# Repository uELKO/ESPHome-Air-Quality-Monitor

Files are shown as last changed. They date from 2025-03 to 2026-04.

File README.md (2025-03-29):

Unbenannt

## Project outline
This project describes a sensor for measuring indoor air quality with power supply via USB-C.

An “Environmental Sensor Node for Air Quality Applications” from Sensirion is used. An ESP32-S3 is responsible for sensor evaluation and wireless connection via WLAN. The mounted modules are listed in the “List of Materials” section.
The housing consists of 3 parts, which can be easily 3D printed. The STEP files are stored in the “3d-models” folder.
The measured values are displayed via the ESPHome integration in Home Assistant and optionally via an e-paper display on the front.

The aim was to develop both a stationary sensor for determining indoor air quality and a mobile sensor for use on the move. The applications range from use as an informative sensor to warning messages when limit values are exceeded or as a sensor for controlling temperature and room air.

## Features
Depending on the model of the Sensirion sensor, different physical quantities can be obtained.
In this project, the SEN66 was used, which records the following measured variables:
- Temperature
- Relative humidity
- Particulate matter (PM1.0, PM2.5, PM4.0, PM10.0)
- VOC
- NOx
- CO2

In addition, there are further virtual sensors through the ESPHome yaml:
- PM ≤10 µm: Sum of the dust particle concentration
- TVOC according to Mølhave
- IAQ index (parameterizable weighting of CO2, TVOC and PM)

All sensor values are updated every 10 seconds, so this sensor is also ideal for creating fast control loops with other devices, e.g:
- Air purifiers
- Radiator valves
- Air conditioning systems

## List of Materials
- MCU:      Seeed Studio XIAO ESP32S3
- Display:  Waveshare 2.13inch E-Ink display HAT
- Sensor:   Sensirion SEN66

-> The total cost is around 70-80€.

Assembly instructions (note: in progress, only photos for now): [assembly_guide.md](docs/assembly_guide.md)

## Limitations
Status: March 2025
- Native temperature compensation not working -> deduction of a linear offset for temperature and humidity, resulting in two virtual sensors (Ambient Temperature, Ambient Humidity)
- Fan Auto Clean not working
- Official ESPHome integration “SEN5x” does not support the SEN6x series, therefore use the repo from Tobias Stanzel (https://github.com/tuct) Thank you!
-> I have made an adjustment so that e.g. the measured value PM4 only represents the range of 2.5-4 µm and not 0-4µm as originally.
- The SEN66 has an integrated air pressure sensor, which currently cannot be read out either

-> I hope for an official integration of the SEN6x series in ESPHome soon!

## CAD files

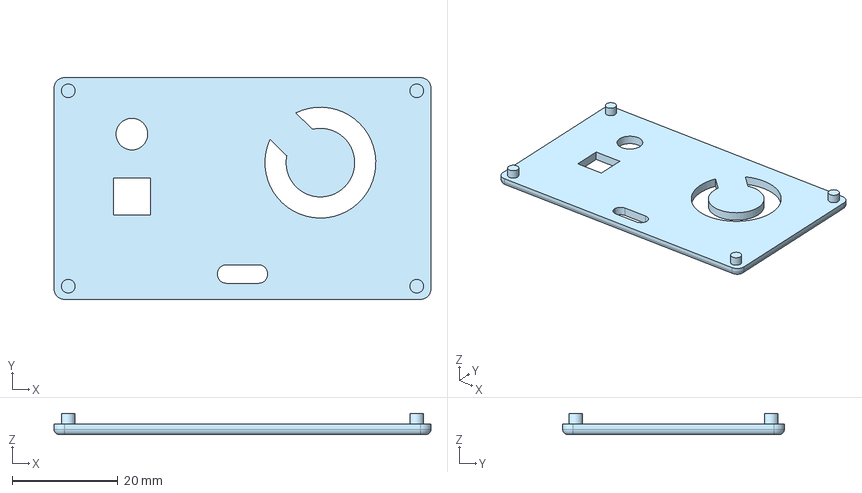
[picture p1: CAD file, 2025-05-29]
3d-models/Back_Cover.step
71.4 x 42.0 x 4.00 mm

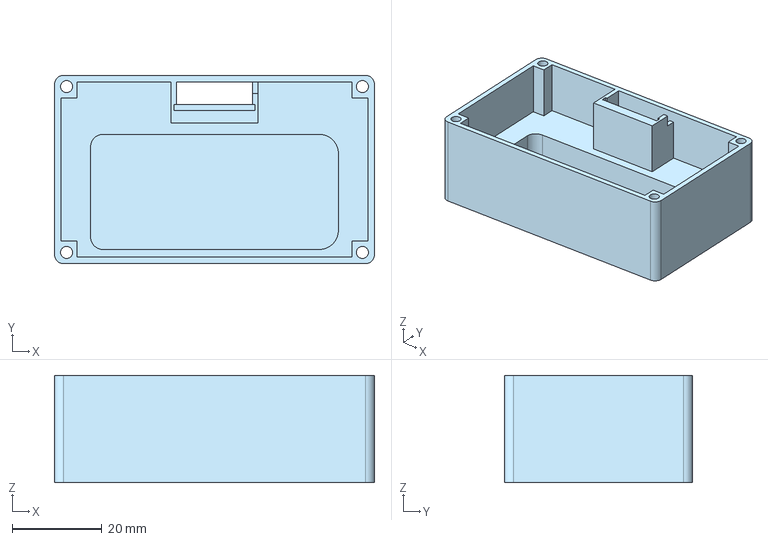
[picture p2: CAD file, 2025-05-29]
3d-models/Mid_Frame.step
71.4 x 42.0 x 23.9 mm

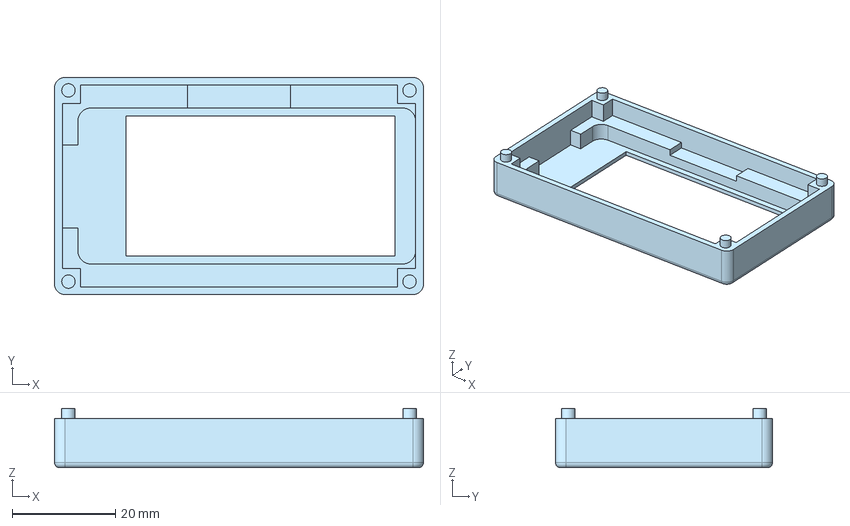
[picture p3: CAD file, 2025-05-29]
3d-models/Display_Frame.step
71.4 x 42.0 x 11.5 mm

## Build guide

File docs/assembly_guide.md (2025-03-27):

## Pinout
SEN6x (I2C):
- sda: GPIO1
- scl: GPIO2

Display (SPI):
- cs_pin: GPIO4
- dc_pin: GPIO5
- busy_pin: GPIO43
- reset_pin: GPIO6
- clk_pin: GPIO8
- mosi_pin: GPIO9

## Assembly Steps (in progress...)















PXL_20250327_121250921 MP

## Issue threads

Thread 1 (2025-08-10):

Sensor not connecting

BrianHollander-NL, 2025-08-10:
I have assembled the sensor to the ESP32-S3. But after starting I get this in the logs:

[17:45:18][E][sen6x:037]: Failed to write data ready status command
[17:45:18][E][component:194]: sen6x.sensor was marked as failed
[17:45:18][E][component:286]: sen6x.sensor set Error flag: unspecified

I also don't see the fan do anything on the sensor. I have not installed resistors.

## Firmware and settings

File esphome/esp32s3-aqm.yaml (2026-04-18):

esphome:
  name: "esp32s3-aqs-1"
  friendly_name: ESP32S3-AQS-1
  min_version: 2024.11.0
  name_add_mac_suffix: false
  on_boot:
    - priority: -100
      then:
        - lambda: |-
            id(sen66).set_temperature_compensation(
              id(temperature_offset_input).state,
              0,  // normalized_offset_slope
              0   // time_constant
            );
    - priority: 800
      then:
          - component.update: my_display

external_components:
  - source:
      type: git
      url: https://github.com/uELKO/esphome_external_components
      ref: rework
    components: sen6x

esp32:
  board: esp32-s3-devkitc-1
  framework:
    type: arduino
  

# Enable logging
logger:

# Enable Home Assistant API
api:

# Allow Over-The-Air updates
ota:
- platform: esphome

wifi:
  ssid: !secret wifi_ssid
  password: !secret wifi_password

  # Enable fallback hotspot (captive portal) in case wifi connection fails
  ap:
    ssid: "ESP32S3-AQS-1"
    password: "asdhfuiSHZUDK234"

# Sets up Bluetooth LE (Only on ESP32) to allow the user
# to provision wifi credentials to the device.
esp32_improv:
  authorizer: none

# To have a "next url" for improv serial
web_server:

i2c: # example, replace
  sda: GPIO1
  scl: GPIO2
  scan: true
  id: bus_a

font:
  - file: 'fonts/DSEG14Classic-Regular.ttf'
    id: font_7s_Temp
    size: 44

  - file: 'fonts/DSEG14Classic-Regular.ttf'
    id: font_7s_Hyg
    size: 32

  - file: 'fonts/DSEG7Modern-Regular.ttf'
    id: font_7s_unit
    size: 24

  - file: 'fonts/Arial.ttf'
    id: font_Arial_24
    size: 24
  - file: 'fonts/Arial.ttf'
    id: font_Arial_18
    size: 18
    glyphs: >-
      !?"%()+*=,-_.:°µ²³0123456789ABCDEFGHIJKLMNOPQRSTUVWXYZabcdefghijklmnÖÄÜöäüopqrstuvwxyz$@<>/≤ 
  - file: 'fonts/Arial.ttf'
    id: font_Arial_16
    size: 16
  - file: 'fonts/Arial.ttf'
    id: font_Arial_14
    size: 14
    glyphs: >-
      !?"%()+*=,-_.:°µ²³0123456789ABCDEFGHIJKLMNOPQRSTUVWXYZabcdefghijklmnÖÄÜöäüopqrstuvwxyz$@<>/≤

    # https://pictogrammers.github.io/@mdi/font/6.5.95/    Unicodes
  - file: 'fonts/materialdesignicons-webfont.ttf'
    id: materialdesign_icons_25
    size: 22
    glyphs: [
      "\U000F050F", # mdi-thermometer
      "\U000F0F55", # mdi-home-thermometer-outline
      "\U000F0F54", # mdi-home-thermometer
      "\U000F058E", # mdi-water-percent
      "\U000F029A", # mdi-gauge
      "\U000F059B", # mdi-weather-sunset
      "\U000F059C", # mdi-weather-sunrise
      "\U000F10C2", # mdi-thermometer-high
      "\U000F10C3", # mdi-thermometer-low
      "\U000F091F", # mdi-wifi-strength-1
      "\U000F0922", # mdi-wifi-strength-2
      "\U000F0925", # mdi-wifi-strength-3
      "\U000F0928", # mdi-wifi-strength-4
      "\U000F092B", # mdi-wifi-strength-alert-outline
      "\U000F1257", # api-off
      "\U000F109B"  # api-on
      ]

spi:
  clk_pin: GPIO8
  mosi_pin: GPIO9

interval:
  - interval: 5s
    then:
      - component.update: my_display

time:
  - platform: homeassistant
    id: homeassistant_time
    timezone: "Europe/Berlin"

sensor:
  - platform: homeassistant
    id: ha_api
    entity_id: sensor.home_assistant_operating_system_version
    internal: true

  - platform: sen6x
    id: sen66
    pm_1_0:
      name: "PM <1 µm"
      id: sen66_pm10
      accuracy_decimals: 1
    pm_2_5:
      name: "PM 1-2.5 µm"
      id: sen66_pm25
      accuracy_decimals: 1
    pm_4_0:
      name: "PM 2.5-4 µm"
      id: sen66_pm40
      accuracy_decimals: 1
    pm_10_0:
      name: "PM 4-10 µm"
      id: sen66_pm100
      accuracy_decimals: 1 
    co2:
      name: "CO₂"
      id: sen66_co2
      accuracy_decimals: 0
    temperature:
      name: "Temperature"
      accuracy_decimals: 1
      id: sen66_temperature_top
    humidity:
      name: "Humidity"
      accuracy_decimals: 0
      id: sen66_humidity
    voc:
      name: "VOC"
      id: sen66_voc
      algorithm_tuning:
        index_offset: 100
        learning_time_offset_hours: 12
        learning_time_gain_hours: 12
        gating_max_duration_minutes: 180
        std_initial: 50
        gain_factor: 230
      filters:
        - sliding_window_moving_average:
            window_size: 9
            send_every: 1
    nox:
      name: "NOX"
      id: sen66_nox
      algorithm_tuning:
        index_offset: 100
        learning_time_offset_hours: 12
        learning_time_gain_hours: 12
        gating_max_duration_minutes: 180
        std_initial: 50
        gain_factor: 230
      filters:
        - sliding_window_moving_average:
            window_size: 9
            send_every: 1
    #temperature_compensation: -> Not working for SEN6x for now
    #  offset: -5.8
    #  normalized_offset_slope: 0
    #  time_constant: 0
    store_baseline: true
    update_interval: 30s
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

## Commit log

2025-03-27 Project files added
    [Back_Cover.step, Display_Frame.step, Mid_Frame.step]
2025-05-29 Updated 3D models
    - SEN66 facing backwards
    - Slot for SEN66 cables
    [Back_Cover.step, Display_Frame.step, Mid_Frame.step]
2025-11-22 Update sensor update intervals and bug fix with current esp home version
    Updated minimum version and increased update intervals for various sensors.
    Fixed bug with wifi strength symbol, which wasn't working with ESPHome 2025.11
    [esp32s3-aqm.yaml]
2026-04-18 Update ESPHome configuration
    - Fixed error with new WiFi component
    - Added Dew Point Sensor
    [esp32s3-aqm.yaml]
